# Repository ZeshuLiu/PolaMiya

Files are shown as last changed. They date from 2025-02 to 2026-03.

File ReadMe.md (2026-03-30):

# PolaMiya - 宝丽来相机改装项目

**代码仓库：[PolaMiyaSoftware](https://github.com/ZeshuLiu/PolaMiyaSoftware)**

**硬件仓库（电路及结构）：[PolaMiyaHardware](https://github.com/ZeshuLiu/PolaMiyaHardware)**

> 本仓库保留项目整体说明，代码和硬件设计文件已分别迁移至上述独立仓库。

宝丽来相机一台，具有测距、电动吐片等功能。

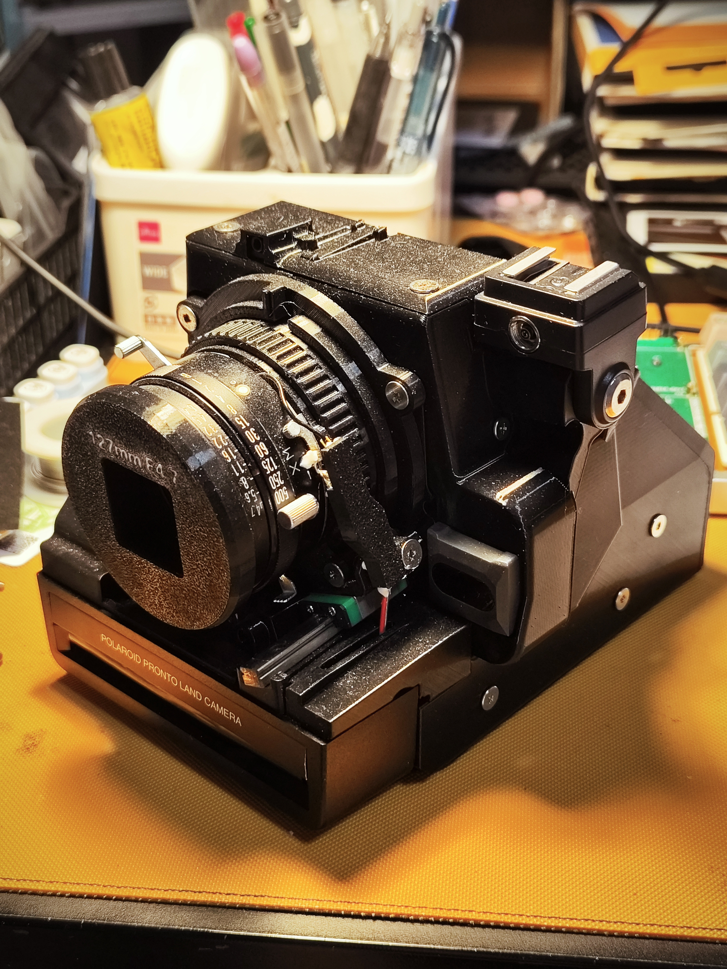
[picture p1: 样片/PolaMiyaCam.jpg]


## 已实现功能

1. 电动吐片
2. 激光测距
3. 温度显示（核心 PCB 及芯片温度）
4. 屏幕显示控制
5. 闪光灯控制（经 MCU）

## 说明

项目比较简单，需要采购的大件只有两个：
- Mamiya Press 127mm 镜头（不需要调焦桶）
- 宝丽来 AF5000（需要里面的吐片下巴、吐片电机和齿轮组）

详细的结构件和装配说明请参考 **[PolaMiyaHardware](https://github.com/ZeshuLiu/PolaMiyaHardware)** 仓库。

## 硬件设计

电路及结构设计文件位于 **[PolaMiyaHardware](https://github.com/ZeshuLiu/PolaMiyaHardware)** 仓库，包含：
- PCB 设计
- 3D 打印结构件
- 装配图纸

## 软件代码

源代码位于 **[PolaMiyaSoftware](https://github.com/ZeshuLiu/PolaMiyaSoftware)** 仓库，包含：
- 主控器固件（MainController2）
- 电源管理固件（PowerManage2）
- CubeMX 配置及 Keil uVision 工程

## 使用方法

机身左下角按钮长按 2 秒开机或关机；三向按钮长按中键 2 秒吐片电机开始运行，随后短按吐片电机停止；在吐片电机运行时推动侧面推杆，相纸即吐出；测距开机即运行。

## 样片

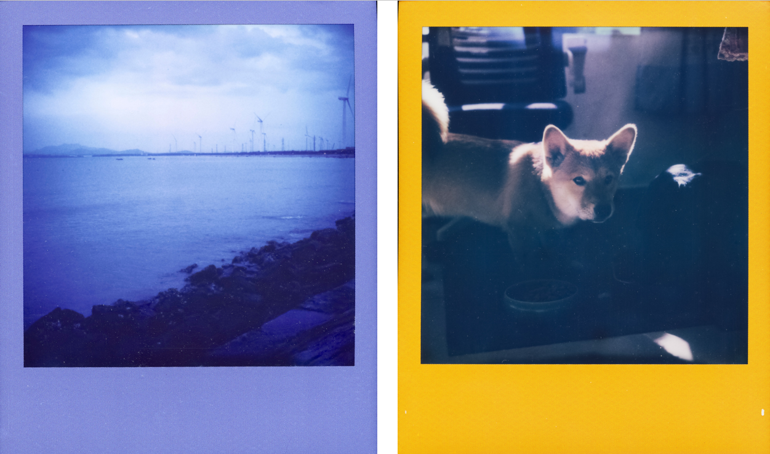
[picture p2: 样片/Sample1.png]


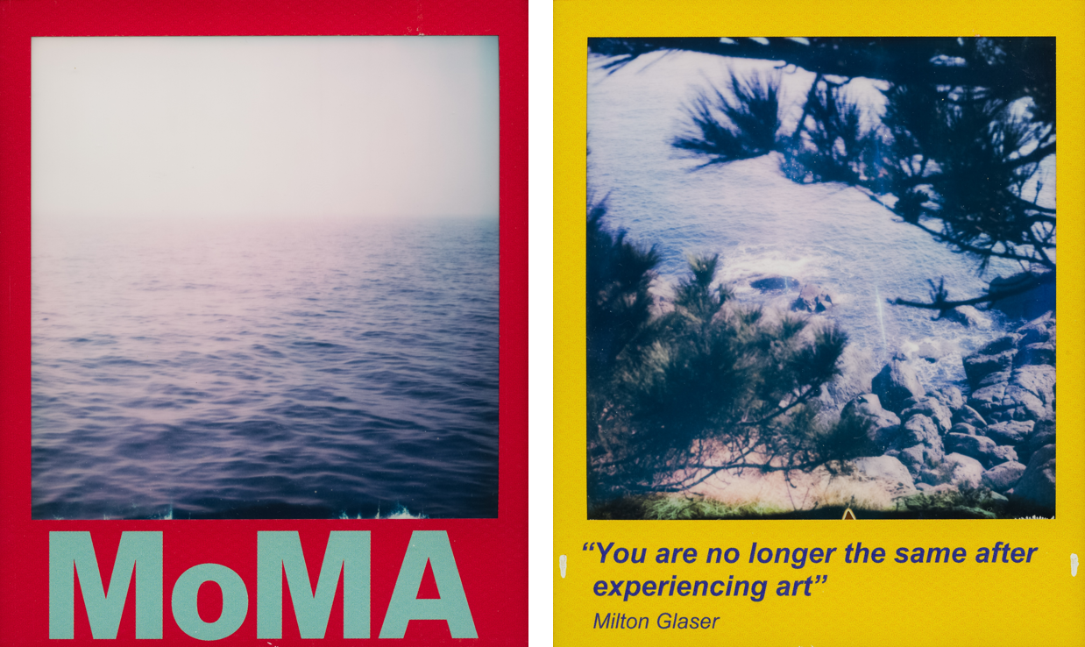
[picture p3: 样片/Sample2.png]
样片 2


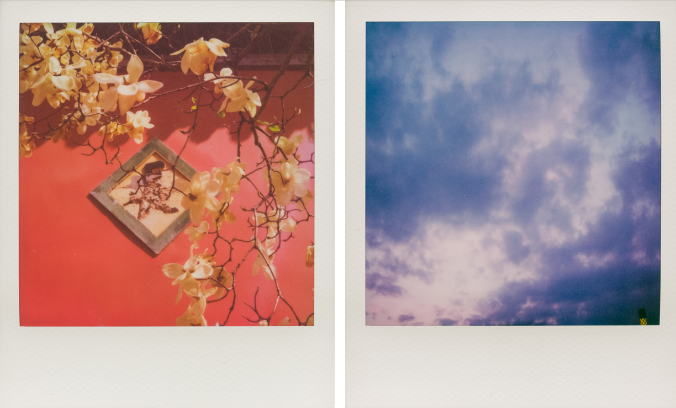
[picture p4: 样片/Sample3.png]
样片 3


## 后续计划

1. 测光
2. 全息取景器（已开始设计）

## 已知问题

1. 吐片口密封性能不好，严禁在有相纸的情况下打开片仓（不中途打开片仓密封性没有问题）

## 已修复问题

1. （主控器 Rev1.0 硬件）相机吐片电机运行后会导致测距停止，该问题由硬件导致，已经在 Rev1.2 硬件中修复
2. （主控器 Rev1.0 硬件）温度传感器布置位置不合理，测得的温度受芯片运行发热影响较大。已经在 Rev1.2 硬件中修复

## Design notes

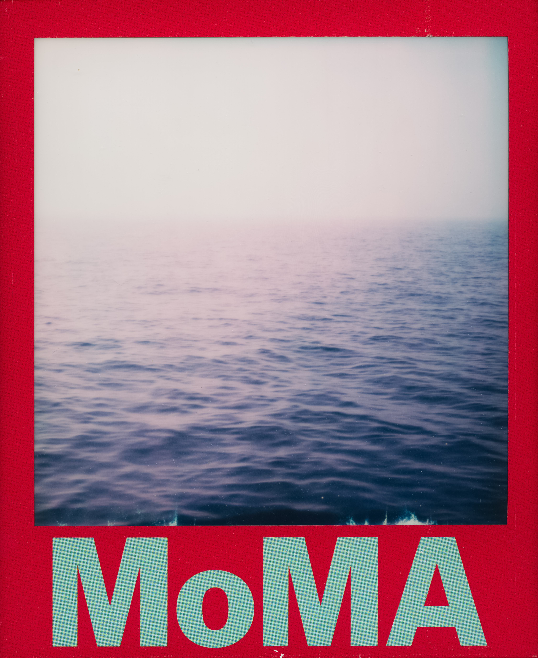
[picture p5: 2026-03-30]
样片/20260329-raw0098.jpg

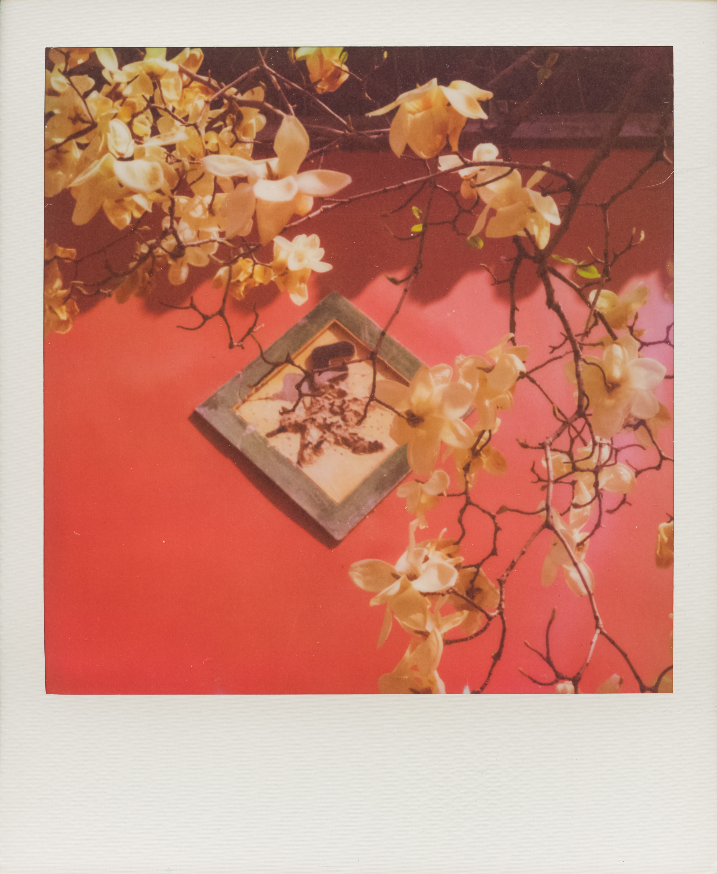
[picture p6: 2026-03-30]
样片/20260329-raw0103.jpg

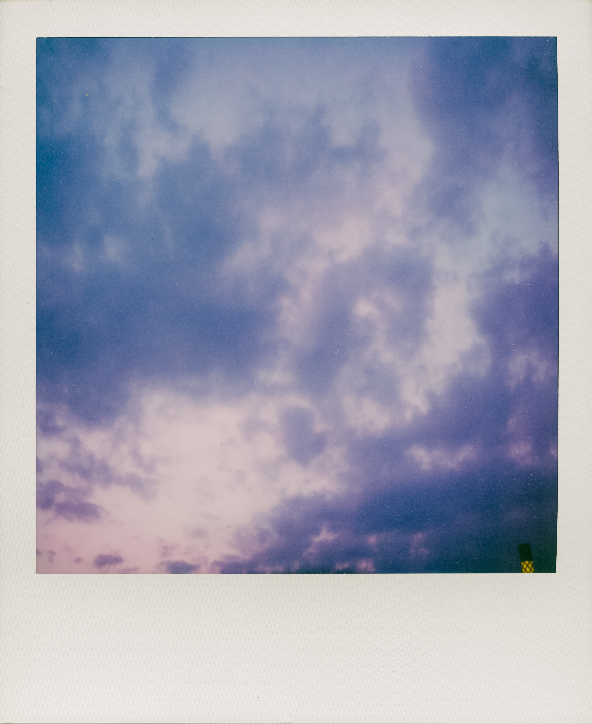
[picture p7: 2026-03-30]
样片/20260329-raw0106.jpg

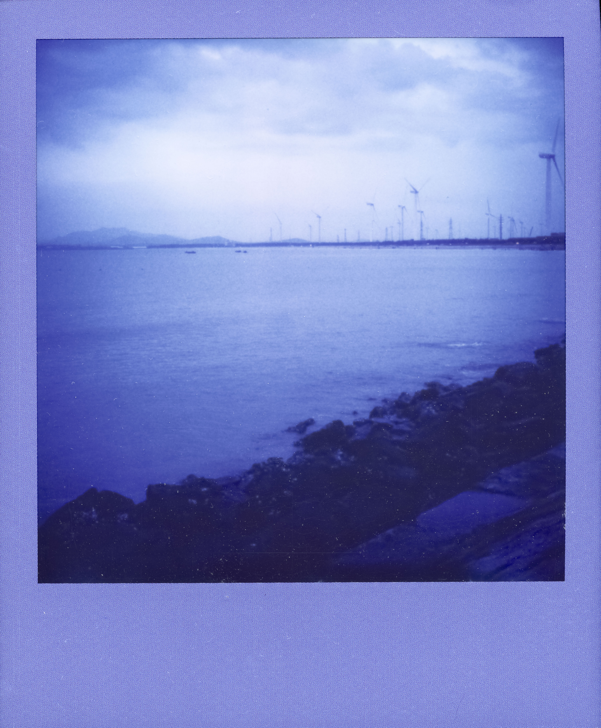
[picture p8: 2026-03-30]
样片/raw0060_1.jpg

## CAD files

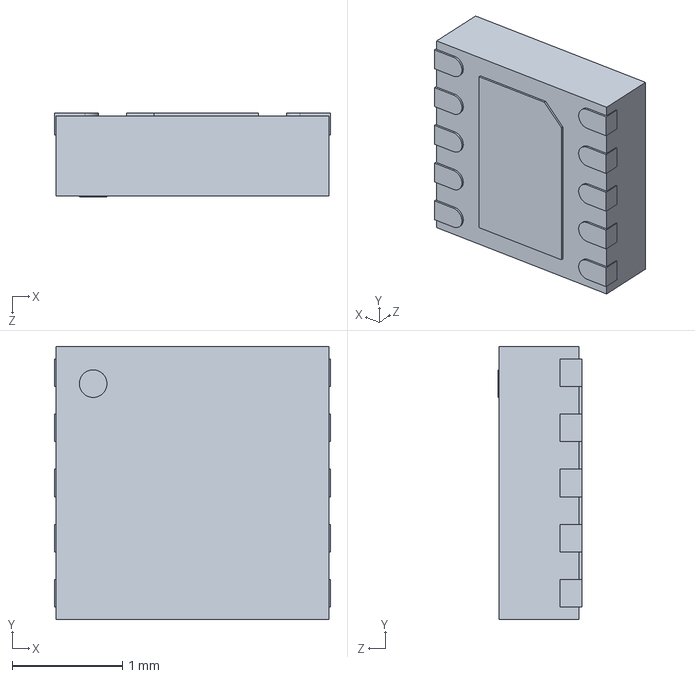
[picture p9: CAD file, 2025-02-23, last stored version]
结构Rev2/电路/机身主控/CQ assembly.SLDPRT
2.50 x 2.47 x 0.76 mm

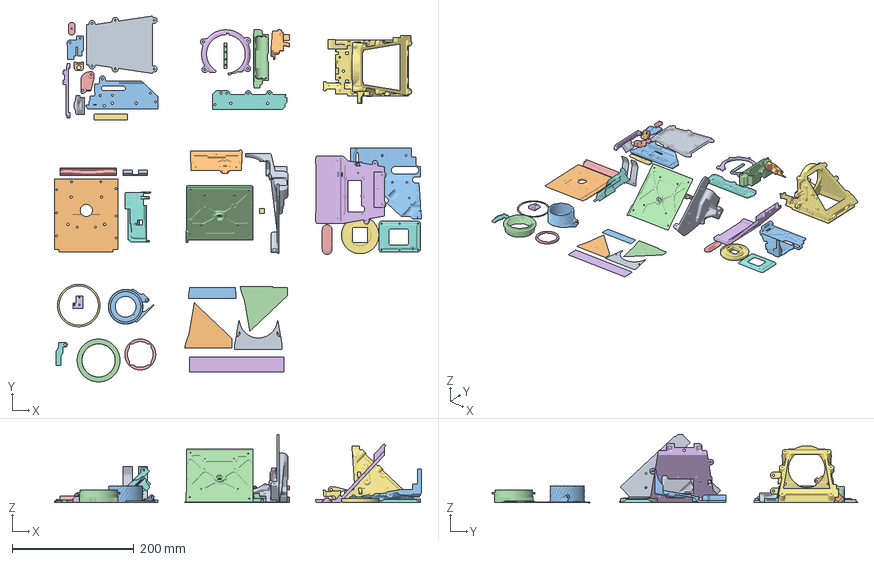
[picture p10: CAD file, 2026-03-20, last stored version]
结构Rev2N/PolaMiya_FullAssemble.3mf
602.8 x 600.9 x 112.5 mm
反光镜盖板.STL
前左盖.STL
右侧板.STL
后侧板.STL
齿轮盖.STL
调焦桶盖.STL
出片推杆.STL
左侧板.STL
齿轮维护盖.STL
电机卡环.STL
推杆外框.STL
推片钩衬垫.STL
推片把手.STL
电池压板.STL
主片仓.STL
前盖板.STL
片仓弹簧.STL
底板.STL
右侧壳.STL
底壳.STL
推片杆外罩.STL
背壳.STL
镜头挡光板.STL
屏幕盖.STL
左侧壳.STL
顶壳.STL
MamiyaPressLensSeat.STL
内环.STL
挡板.STL
滑块连接.STL
镜头衬垫.STL
闪光灯线.STL
前侧.STL
右内壁.STL
后侧.STL
左内壁.STL
齿轮定位.STL
镜筒.STL
按钮.STL

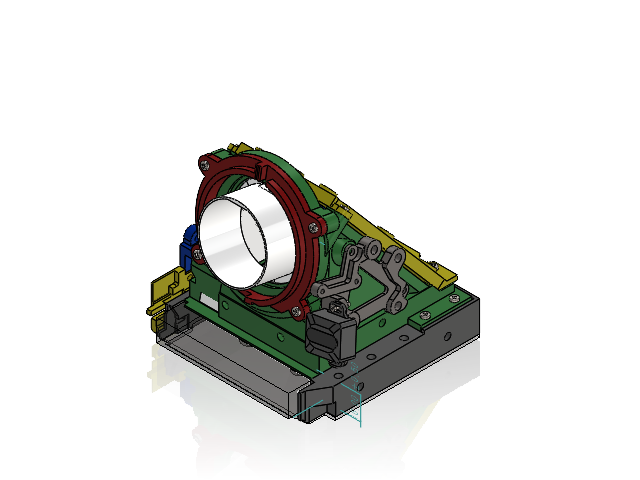
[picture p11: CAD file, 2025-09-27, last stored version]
结构/片仓/片仓1.SLDASM
片仓主框
调焦桶盖
出片推杆
反射镜压板
反射镜压板盖
片仓侧杆
片仓中框
推片把手
推片钩定位
相纸盒
主反射镜
推片勾
cross recessed cheese head screws type a gb x 23
左侧副支架
激光测距SDM18
片仓地板
推杆外框
镜头遮光内筒
片仓消光绒1
片仓消光绒2
片仓消光绒3
片仓消光绒4 x 2
片仓消光绒5

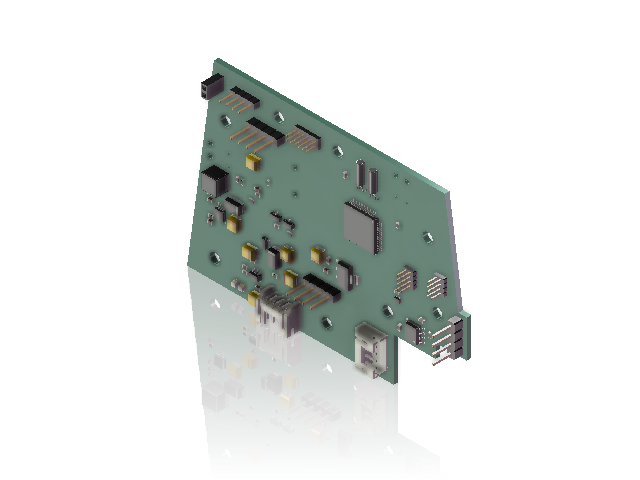
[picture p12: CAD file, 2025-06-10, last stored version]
结构/电路/PM_Controller_R1_0/PM_Controller_Rev1_0.SLDASM
PinHeader_2x04_P1.27mm_Vertical.step x 2
R_0603_1608Metric.step x 42
C_0603_1608Metric.step x 30
SOT-23.step x 6
LQFP-64_10x10mm_P0.5mm.step
PinHeader_1x04_P2.00mm_Vertical.step
PinHeader_2x06_P1.27mm_Vertical.step
CP_EIA-3528-21_Kemet-B.step x 8
PinHeader_1x04_P2.54mm_Vertical.step x 3
LED_0805_2012Metric.step x 2
SOIC-8_3.9x4.9mm_P1.27mm.step x 2
SOT-23-6.step
JST_PH_S4B-PH-K_1x04_P2.00mm_Horizontal.step x 2
D_SMA.step x 3
SOT-563.step
Crystal_C26-LF_D2.1mm_L6.5mm_Horizontal.step x 3
SOT-223.step
PinSocket_1x02_P2.00mm_Vertical.step
L_APV_ANR5040.step
VSSOP-8_3x3mm_P0.65mm.step
TSSOP-14_4.4x5mm_P0.65mm.step
SOT-23-5.step
MFSOP6-4_4.4x3.6mm_P1.27mm.step
L_0805_2012Metric.step
PM_Controller_PCB.step

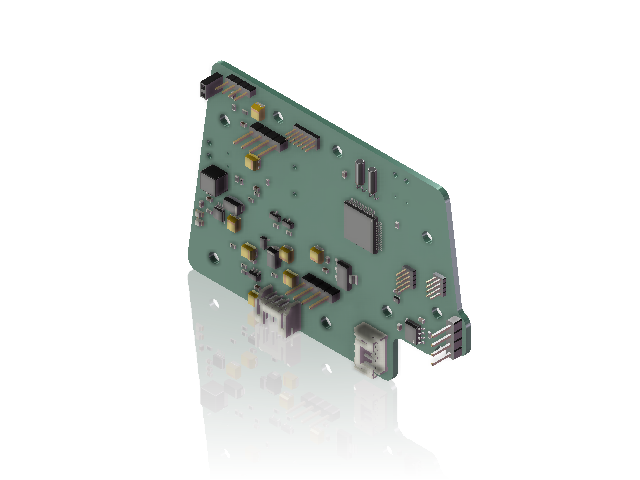
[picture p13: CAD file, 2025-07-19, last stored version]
结构/电路/PM_Controller_R1_1/PM_Controller1_1.SLDASM
PinHeader_2x04_P1.27mm_Vertical.step x 2
R_0603_1608Metric.step x 44
C_0603_1608Metric.step x 32
SOT-23.step x 6
LQFP-64_10x10mm_P0.5mm.step
PinHeader_1x04_P2.00mm_Vertical.step
PinHeader_2x06_P1.27mm_Vertical.step
CP_EIA-3528-21_Kemet-B.step x 9
PinHeader_1x04_P2.54mm_Vertical.step x 3
LED_0805_2012Metric.step x 2
SOIC-8_3.9x4.9mm_P1.27mm.step x 2
SOT-23-6.step
JST_PH_S4B-PH-K_1x04_P2.00mm_Horizontal.step x 2
D_SMA.step x 3
SOT-563.step
Crystal_C26-LF_D2.1mm_L6.5mm_Horizontal.step x 3
SOT-223.step
PinSocket_1x02_P2.00mm_Vertical.step
L_APV_ANR5040.step
VSSOP-8_3x3mm_P0.65mm.step
TSSOP-14_4.4x5mm_P0.65mm.step
SOT-23-5.step
MFSOP6-4_4.4x3.6mm_P1.27mm.step
L_0805_2012Metric.step
PM_Controller_PCB.step

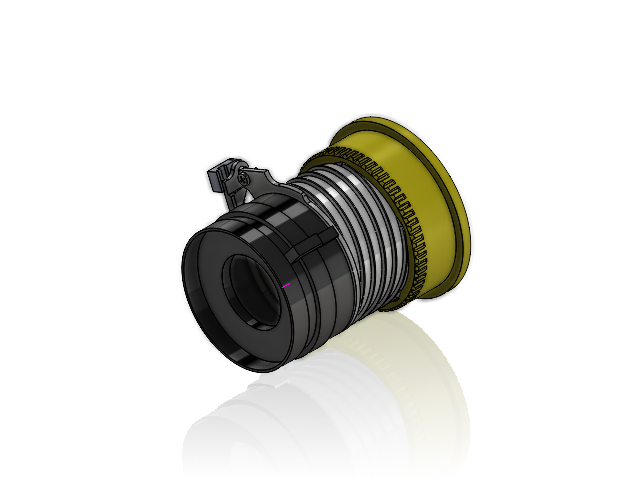
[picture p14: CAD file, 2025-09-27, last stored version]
结构/镜头总成/lensASM.SLDASM
内环
MamiyaPress127
MamiyaPressLensSeat
滑块连接
MGN7C
cross recessed cheese head screws type a gb x 6
闪光灯线

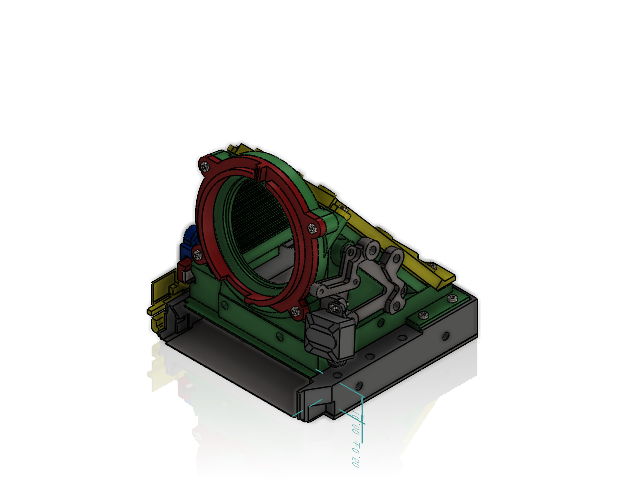
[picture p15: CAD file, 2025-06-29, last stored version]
结构Rev2/片仓/片仓1.SLDASM
片仓主框
调焦桶盖
出片推杆
反射镜压板
反射镜压板盖
片仓侧杆
片仓中框
推片把手
推片钩定位
主反射镜
推片勾
cross recessed cheese head screws type a gb x 23
推片勾内密封
左侧副支架
激光测距SDM18
片仓地板
推杆外框

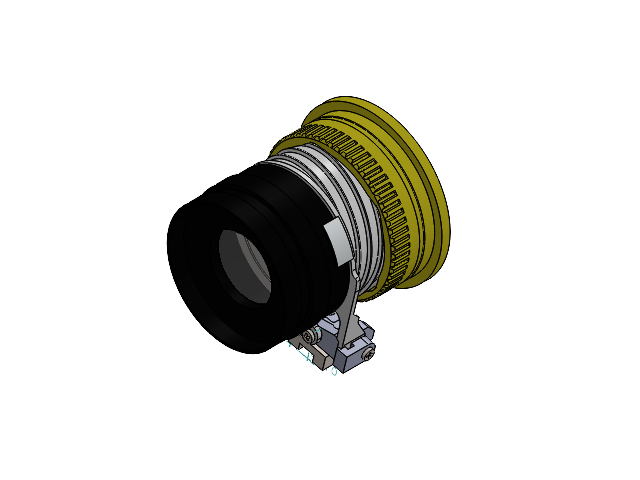
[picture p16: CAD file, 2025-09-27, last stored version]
结构Rev2/镜头总成/lensASM.SLDASM
内环
MamiyaPress127
MamiyaPressLensSeat
滑块连接
MGN7C
cross recessed cheese head screws type a gb x 6
闪光灯线

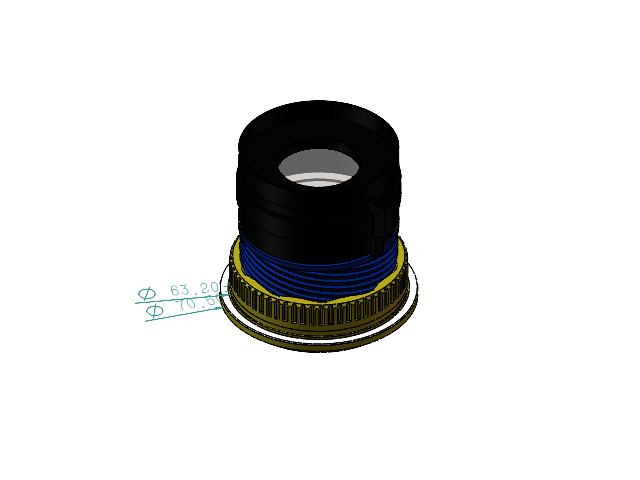
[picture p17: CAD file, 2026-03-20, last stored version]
结构Rev2N/镜头总成/镜头总成.SLDASM
内环
MamiyaPressLensSeat
滑块连接
MamiyaPress127
MGN7C
镜头衬垫

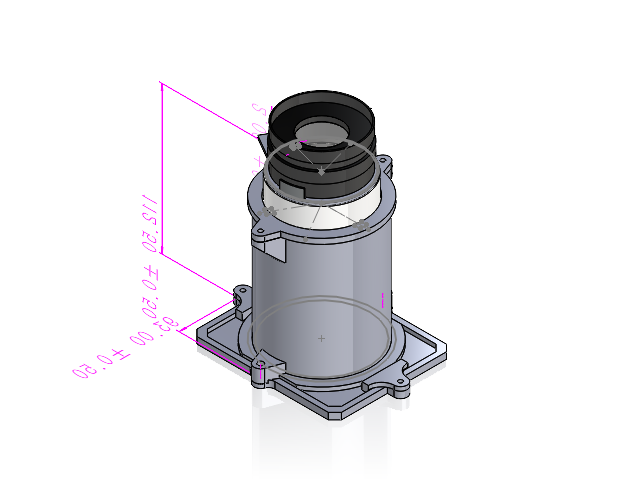
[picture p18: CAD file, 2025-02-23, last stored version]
结构Rev2/测试用/法兰距测试/法兰距测试.SLDASM
镜筒
内环
MamiyaPress127
MamiyaPressLensSeat
盖板
对焦框10080
对焦玻璃压板 x 2

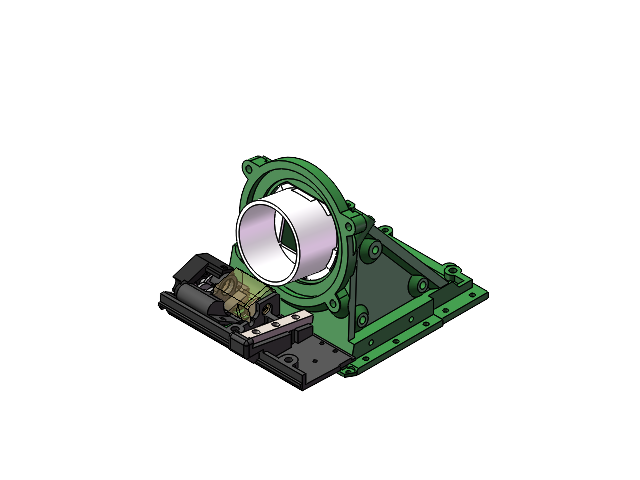
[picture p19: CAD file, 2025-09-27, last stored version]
结构Rev2/片仓吐片总成/片仓吐片装配.SLDASM
片仓吐片一体2^片仓吐片一体
马达座
MG825
吐片上巴
齿轮A
齿轮B
齿轮C
齿轮D
齿轮E
齿轮罩
吐片钣金固定销
MGN7导轨
吐片钣金固定销R
镜头遮光内筒

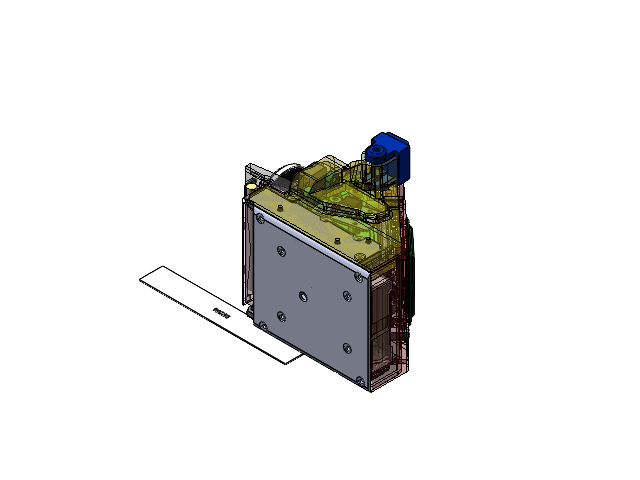
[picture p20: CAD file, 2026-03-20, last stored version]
结构Rev2N/装配.SLDASM
主片仓
主反射镜
相纸盒
吐片口机身钣金-拆机
MG825-拆机
1.6x20.6-拆机
齿轮A-拆机
1.6x14.6-拆机
齿轮B-拆机
齿轮C-拆机
齿轮D-拆机
齿轮E-拆机
PinHeader_2x04_P1.27mm_Vertical.step x 2
R_0603_1608Metric.step x 42
C_0603_1608Metric.step x 30
SOT-23.step x 6
LQFP-64_10x10mm_P0.5mm.step
PinHeader_1x04_P2.00mm_Vertical.step
PinHeader_2x06_P1.27mm_Vertical.step
CP_EIA-3528-21_Kemet-B.step x 8
PinHeader_1x04_P2.54mm_Vertical.step x 3
LED_0805_2012Metric.step x 2
SOIC-8_3.9x4.9mm_P1.27mm.step x 2
SOT-23-6.step
JST_PH_S4B-PH-K_1x04_P2.00mm_Horizontal.step x 2
D_SMA.step x 3
SOT-563.step
Crystal_C26-LF_D2.1mm_L6.5mm_Horizontal.step x 3
SOT-223.step
PinSocket_1x02_P2.00mm_Vertical.step
L_APV_ANR5040.step
VSSOP-8_3x3mm_P0.65mm.step
TSSOP-14_4.4x5mm_P0.65mm.step
SOT-23-5.step
MFSOP6-4_4.4x3.6mm_P1.27mm.step
L_0805_2012Metric.step
PM_Controller_PCB.step
反光镜盖板
推片勾
MGN7导轨1
调焦桶盖
出片推杆
推片把手
齿轮盖
推片钩衬垫
电机卡环
齿轮维护盖
右侧板
18650电池
后侧板
电池负极弹片
电池正极弹片
激光测距SDM18
D_SOD_323.step x 2
CP_Elec_63x77.step x 2
C_1206_3216Metric-0.step x 2
R_0603_1608Metric-1.step x 4
LED_0805_2012Metric-2.step x 2
L_APV_APH1265-3.step
_autosave-MotroDrive_PCB.step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

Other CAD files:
结构Rev2N/电路/PM_Controller_R1_0/PM_Controller_Rev1_0.SLDASM
结构Rev2N/电路/机身主控/Hirose_FH12-8S-0.5SH_1x08-1MP_P0.50mm_Horizontal.SLDASM
结构Rev2N/电路/机身主控/TSSOP-14_4.4x5mm_P0.65mm.SLDASM
电路/sdm18串口.SLDPRT
电路/主控器/DispKey/DispKeyR1_0.step
电路/电机驱动/MotroDrive/Model/MotroDrive.step
电路/闪光灯转接/FlashAdapter/FlashAdapter.step
电路/闪光灯转接/FlashAdapter/upper.SLDPRT
结构/t/PolamiaPCB.SLDASM
结构/t/PolamiaPCB.step
结构/主电子总成/18650电池.SLDPRT
结构/原厂零件/吐片口机身钣金.SLDPRT
结构/吐片机构/1.6x14.6.SLDPRT
结构/吐片机构/1.6x20.6.SLDPRT
结构/吐片机构/MG825.SLDPRT
结构/吐片机构/STLs/1吐片钣金固定销.3mf
结构/吐片机构/STLs/1吐片钣金固定销.STL
结构/吐片机构/STLs/1固定销+2钣金连接.3mf
结构/吐片机构/STLs/2吐片钣金连接件.3mf
结构/吐片机构/STLs/2吐片钣金连接件.STL
结构/吐片机构/STLs/3A齿轮罩.3mf
结构/吐片机构/STLs/3A齿轮罩.STL
结构/吐片机构/STLs/3齿轮罩.3mf
结构/吐片机构/STLs/3齿轮罩.STL
结构/吐片机构/STLs/4马达座.STL
结构/吐片机构/STLs/5马达座.3mf
结构/吐片机构/STLs/5马达座.STL
结构/吐片机构/STLs/6吐片上巴+5线轴.3mf
结构/吐片机构/STLs/6吐片上巴.3mf
结构/吐片机构/STLs/6吐片上巴.STL
结构/吐片机构/STLs/吐片齿轮总成.3mf
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

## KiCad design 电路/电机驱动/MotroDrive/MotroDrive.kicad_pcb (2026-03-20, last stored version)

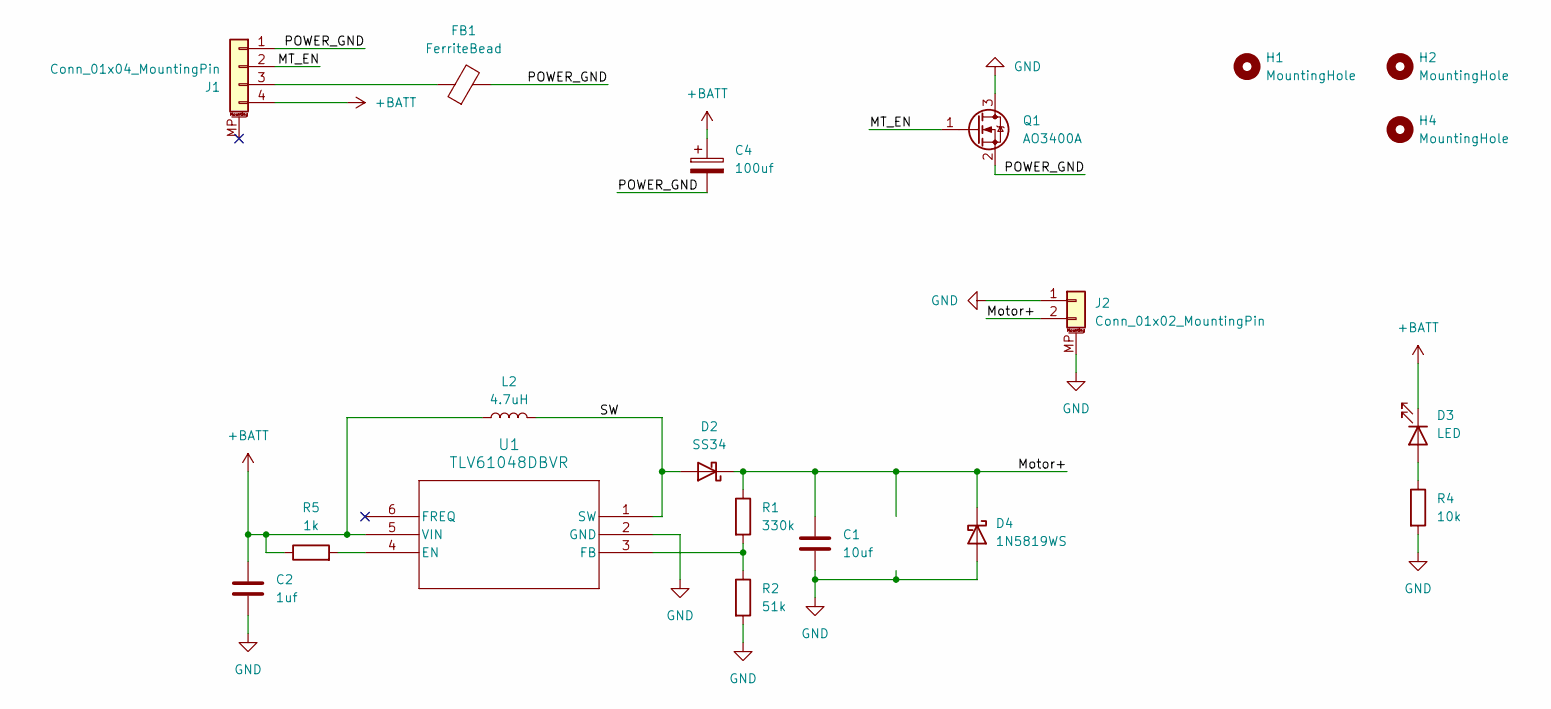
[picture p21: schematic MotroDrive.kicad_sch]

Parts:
C1: 10uf; C_1206_3216Metric_Pad1.33x1.80mm_HandSolder
C2: 1uf; C_1206_3216Metric_Pad1.33x1.80mm_HandSolder
C4: 100uf; CP_Elec_6.3x7.7
D2: SS34; D_SMA
D3: LED; LED_0805_2012Metric_Pad1.15x1.40mm_HandSolder
D4: 1N5819WS; D_SOD-323_HandSoldering
FB1: FerriteBead; L_0603_1608Metric
H1, H2, H4: MountingHole; MountingHole_3.2mm_M3
J1: Conn_01x04_MountingPin; JST_PH_S4B-PH-SM4-TB_1x04-1MP_P2.00mm_Horizontal
J2: Conn_01x02_MountingPin; JST_PH_S2B-PH-SM4-TB_1x02-1MP_P2.00mm_Horizontal
L2: 4.7uH; L_APV_APH1265
Q1: AO3400A; SOT-23
R1: 330k; R_0603_1608Metric_Pad0.98x0.95mm_HandSolder
R2: 51k; R_0603_1608Metric_Pad0.98x0.95mm_HandSolder
R4: 10k; R_0603_1608Metric_Pad0.98x0.95mm_HandSolder
R5: 1k; R_0603_1608Metric
U1: TLV61048DBVR; SOT-23-6_DBV_TEX

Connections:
+BATT: C2.1, C4.1, D3.1 (K), J1.4, L2.1, R5.1, U1.5 (VIN)
/MT_EN: J1.2, Q1.1 (G)
/Motor+: C1.1, D2.1 (K), D4.1 (K), J2.2, R1.1
/POWER_GND: C4.2, FB1.2, J1.1, Q1.2 (S)
/SW: D2.2 (A), L2.2, U1.1 (SW)
GND: C1.2, C2.2, D4.2 (A), J2.1, J2.MP (MountPin), Q1.3 (D), R2.2, R4.2, U1.2 (GND)
unnamed: D3.2 (A), R4.1
unnamed: FB1.1, J1.3
unnamed: R5.2, U1.4 (EN)
unnamed: R1.2, R2.1, U1.3 (FB)

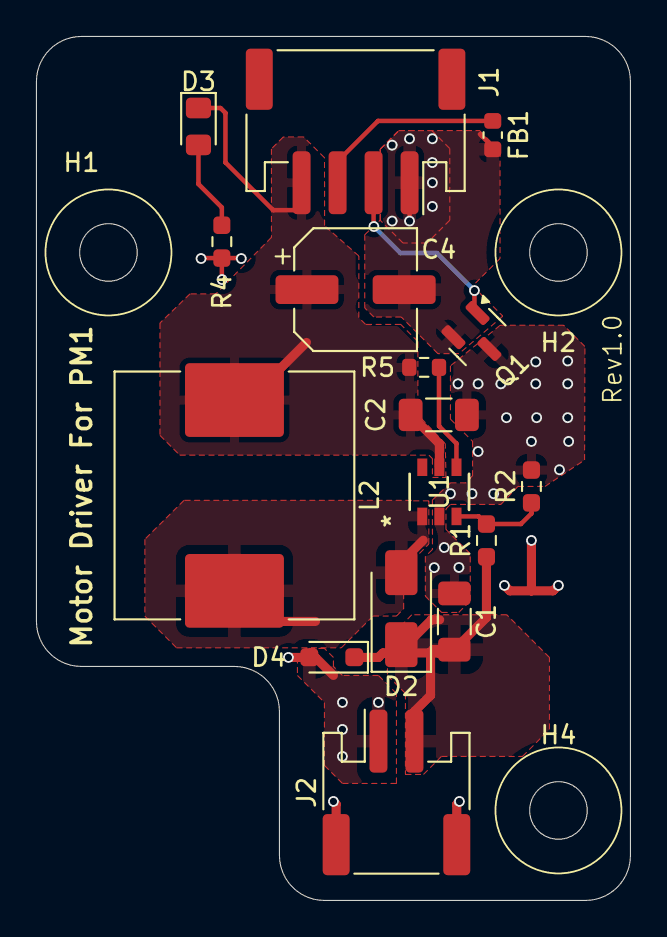
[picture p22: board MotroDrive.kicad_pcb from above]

Board: 2 copper layers, 33.0 x 48.0 mm, 19 parts (0 on the bottom side), 10 nets.

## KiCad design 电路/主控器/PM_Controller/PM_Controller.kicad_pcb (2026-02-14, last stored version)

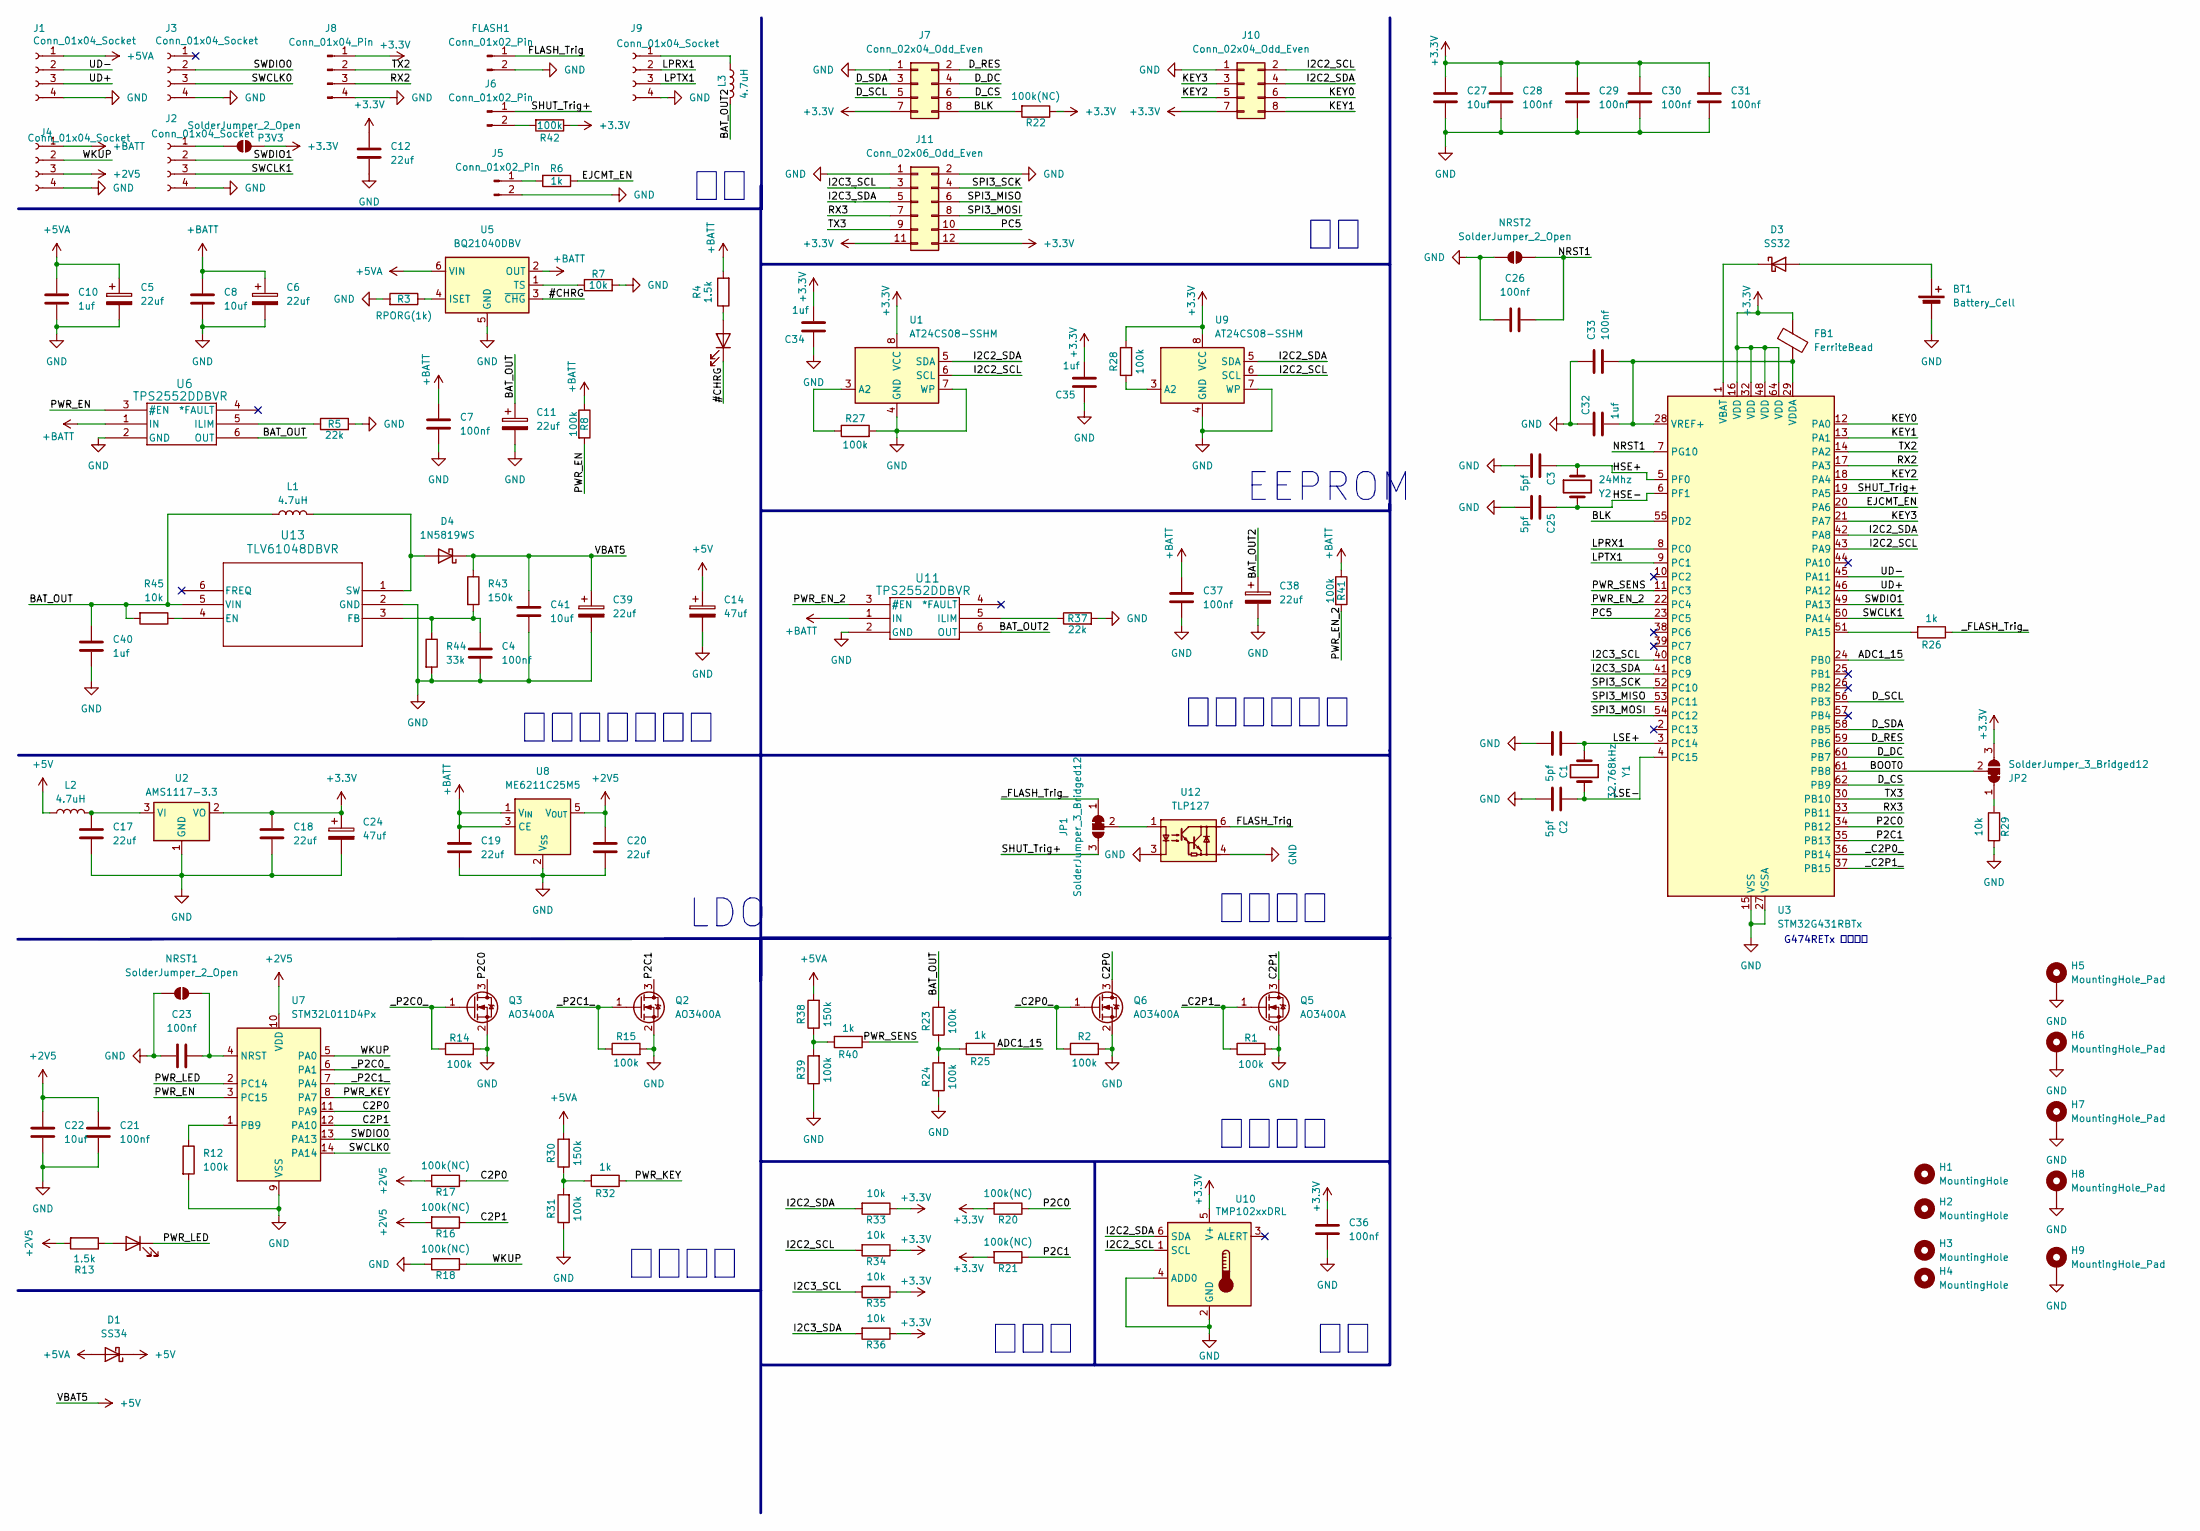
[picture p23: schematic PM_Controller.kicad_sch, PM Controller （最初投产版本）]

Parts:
BT1: Battery_Cell; cr1220
C1, C2, C3, C25: 5pf; C_0603_1608Metric_Pad1.08x0.95mm_HandSolder
C4: 100nf; C_0603_1608Metric
C5, C6, C11, C38: 22uf; CP_EIA-3528-21_Kemet-B_Pad1.50x2.35mm_HandSolder
C7, C21, C23, C26, C28, C29, C30, C31, C33, C36, C37: 100nf; C_0603_1608Metric_Pad1.08x0.95mm_HandSolder
C8, C22, C27: 10uf; C_0603_1608Metric_Pad1.08x0.95mm_HandSolder
C10, C32, C34, C35: 1uf; C_0603_1608Metric_Pad1.08x0.95mm_HandSolder
C12: 22uf; C_1206_3216Metric_Pad1.33x1.80mm_HandSolder
C14, C24: 47uf; CP_EIA-3528-21_Kemet-B_Pad1.50x2.35mm_HandSolder
C17, C18, C19, C20: 22uf; C_0603_1608Metric_Pad1.08x0.95mm_HandSolder
C39: 22uf; CP_EIA-3528-21_Kemet-B_HandSolder
C40: 1uf; C_1206_3216Metric_Pad1.33x1.80mm_HandSolder
C41: 10uf; C_1206_3216Metric_Pad1.33x1.80mm_HandSolder
CHG1: LED; LED_0805_2012Metric_Pad1.15x1.40mm_HandSolder
D1: SS34; D_SMA
D3: SS32; D_SMA_Handsoldering
D4: 1N5819WS; D_SOD-323_HandSoldering
FB1: FerriteBead; L_0805_2012Metric_Pad1.05x1.20mm_HandSolder
FLASH1: Conn_01x02_Pin; SolderWire-0.1sqmm_1x02_P3.6mm_D0.4mm_OD1mm_Relief
H1, H2, H3, H4: MountingHole; MountingHole_3.2mm_M3
H5, H6, H7, H8, H9: MountingHole_Pad; MountingHole_3.2mm_M3_DIN965_Pad_TopBottom
J1, J4: Conn_01x04_Socket; JST_PH_S4B-PH-K_1x04_P2.00mm_Horizontal
J2, J3, J9: Conn_01x04_Socket; PinHeader_1x04_P2.54mm_Vertical
J5: Conn_01x02_Pin; SolderWire-0.5sqmm_1x02_P4.8mm_D0.9mm_OD2.3mm
J6: Conn_01x02_Pin; PinSocket_1x02_P2.00mm_Vertical
J7, J10: Conn_02x04_Odd_Even; PinHeader_2x04_P1.27mm_Vertical
J8: Conn_01x04_Pin; PinHeader_1x04_P2.00mm_Vertical
J11: Conn_02x06_Odd_Even; PinHeader_2x06_P1.27mm_Vertical
JP1, JP2: SolderJumper_3_Bridged12; SolderJumper-3_P1.3mm_Bridged12_Pad1.0x1.5mm
L1, L2, L3: 4.7uH; L_APV_APH0650
NRST1, NRST2: SolderJumper_2_Open; SolderJumper-2_P1.3mm_Open_RoundedPad1.0x1.5mm
P3V3: SolderJumper_2_Open; SolderJumper-2_P1.3mm_Open_RoundedPad1.0x1.5mm
PW_LED1: LED; LED_0805_2012Metric_Pad1.15x1.40mm_HandSolder
Q2, Q3, Q5, Q6: AO3400A; SOT-23
R1, R2, R8, R12, R14, R15, R23, R24, R27, R28, R31, R39, R41, R42: 100k; R_0603_1608Metric_Pad0.98x0.95mm_HandSolder
R3: RPORG(1k); R_0603_1608Metric_Pad0.98x0.95mm_HandSolder
R4, R13: 1.5k; R_0603_1608Metric_Pad0.98x0.95mm_HandSolder
R5, R37: 22k; R_0603_1608Metric_Pad0.98x0.95mm_HandSolder
R6, R25, R26, R32, R40: 1k; R_0603_1608Metric_Pad0.98x0.95mm_HandSolder
R7, R29, R33, R34, R35, R36, R45: 10k; R_0603_1608Metric_Pad0.98x0.95mm_HandSolder
R16, R17, R18, R20, R21, R22: 100k(NC); R_0603_1608Metric_Pad0.98x0.95mm_HandSolder
R30, R38, R43: 150k; R_0603_1608Metric_Pad0.98x0.95mm_HandSolder
R44: 33k; R_0603_1608Metric_Pad0.98x0.95mm_HandSolder
U1, U9: AT24CS08-SSHM; SOIC-8_3.9x4.9mm_P1.27mm
U2: AMS1117-3.3; SOT-223-3_TabPin2
U3: STM32G431RBTx; LQFP-64_10x10mm_P0.5mm
U5: BQ21040DBV; SOT-23-6_Handsoldering
U6, U11: TPS2552DDBVR; DBV0006A_TEX
U7: STM32L011D4Px; TSSOP-14_4.4x5mm_P0.65mm
U8: ME6211C25M5; SOT-23-5_HandSoldering
U10: TMP102xxDRL; SOT-563
U12: TLP127; MFSOP6-4_4.4x3.6mm_P1.27mm
U13: TLV61048DBVR; SOT-23-6_DBV_TEX
Y1: 32.768kHz; Crystal_C26-LF_D2.1mm_L6.5mm_Horizontal
Y2: 24Mhz; Crystal_DS26_D2.0mm_L6.0mm_Horizontal

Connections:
+2V5: C20.1, C21.1, C22.1, J4.3, R13.2, R16.2, R17.2, U7.10 (VDD), U8.5 (V_{OUT})
+3.3V: C12.1, C18.1, C24.1, C27.1, C28.1, C29.1, C30.1, C31.1, C34.2, C35.2, C36.2, FB1.1, J7.7, J8.1, J10.7, J11.11, J11.12, JP2.3 (B), P3V3.2 (B), R20.2, R21.2, R22.1, R28.2, R33.1, R34.1, R35.1, R36.1, R42.1, U1.8 (VCC), U2.2 (VO), U3.16 (VDD), U3.32 (VDD), U3.48 (VDD), U3.64 (VDD), U9.8 (VCC), U10.5 (V+)
+5V: C14.1, C39.1, C41.1, D1.1 (K), D4.1 (K), L2.1, R43.1
+5VA: C5.1, C10.1, D1.2 (A), J1.1, R30.2, R38.2, U5.6 (VIN)
+BATT: C6.1, C7.1, C8.1, C19.1, C37.1, J4.1, R4.2, R8.1, R41.1, U5.2 (OUT), U6.1 (IN), U8.1 (V_{IN}), U8.3 (CE), U11.1 (IN)
/#CHRG: CHG1.1 (K), U5.3 (~CHG)
/ADC1_15: R25.1, U3.24 (PB0)
/BAT_OUT: C11.1, C40.1, L1.1, R23.2, R45.2, U6.6 (OUT), U13.5 (VIN)
/BAT_OUT2: C38.1, L3.2, U11.6 (OUT)
/BLK: J7.8, R22.2, U3.55 (PD2)
/BOOT0: JP2.2 (C), U3.61 (PB8)
/C2P0: Q6.3 (D), R17.1, U7.11 (PA9)
/C2P1: Q5.3 (D), R16.1, U7.12 (PA10)
/D_CS: J7.6, U3.62 (PB9)
/D_DC: J7.4, U3.60 (PB7)
/D_RES: J7.2, U3.59 (PB6)
/D_SCL: J7.5, U3.56 (PB3)
/D_SDA: J7.3, U3.58 (PB5)
/EJCMT_EN: R6.1, U3.20 (PA6)
/FLASH_Trig: FLASH1.1, U12.6
/HSE+: C3.1, U3.5 (PF0), Y2.1
/HSE-: C25.1, U3.6 (PF1), Y2.2
/I2C2_SCL: J10.2, R34.2, U1.6 (SCL), U3.43 (PA9), U9.6 (SCL), U10.1 (SCL)
/I2C2_SDA: J10.4, R33.2, U1.5 (SDA), U3.42 (PA8), U9.5 (SDA), U10.6 (SDA)
/I2C3_SCL: J11.3, R35.2, U3.40 (PC8)
/I2C3_SDA: J11.5, R36.2, U3.41 (PC9)
/KEY0: J10.6, U3.12 (PA0)
/KEY1: J10.8, U3.13 (PA1)
/KEY2: J10.5, U3.18 (PA4)
/KEY3: J10.3, U3.21 (PA7)
/LPRX1: J9.2, U3.8 (PC0)
/LPTX1: J9.3, U3.9 (PC1)
/LSE+: C1.1, U3.3 (PC14), Y1.1
/LSE-: C2.1, U3.4 (PC15), Y1.2
/NRST1: C26.2, NRST2.2 (B), U3.7 (PG10)
/P2C0: Q3.3 (D), R20.1, U3.34 (PB12)
/P2C1: Q2.3 (D), R21.1, U3.35 (PB13)
/PC5: J11.10, U3.23 (PC5)
/PWR_EN: R8.2, U6.3 (#EN), U7.3 (PC15)
/PWR_EN_2: R41.2, U3.22 (PC4), U11.3 (#EN)
/PWR_KEY: R32.1, U7.8 (PA7)
/PWR_LED: PW_LED1.1 (K), U7.2 (PC14)
/PWR_SENS: R40.1, U3.11 (PC3)
/RX2: J8.3, U3.17 (PA3)
/RX3: J11.7, U3.33 (PB11)
/SHUT_Trig+: J6.1, JP1.3 (B), U3.19 (PA5)
/SPI3_MISO: J11.6, U3.53 (PC11)
/SPI3_MOSI: J11.8, U3.54 (PC12)
/SPI3_SCK: J11.4, U3.52 (PC10)
/SWCLK0: J3.3, U7.14 (PA14)
/SWCLK1: J2.3, U3.50 (PA14)
/SWDIO0: J3.2, U7.13 (PA13)
/SWDIO1: J2.2, U3.49 (PA13)
/TX2: J8.2, U3.14 (PA2)
/TX3: J11.9, U3.30 (PB10)
/UD+: J1.3, U3.46 (PA12)
/UD-: J1.2, U3.45 (PA11)
/WKUP: J4.2, R18.1, U7.5 (PA0)
/_C2P0_: Q6.1 (G), R2.1, U3.36 (PB14)
/_C2P1_: Q5.1 (G), R1.1, U3.37 (PB15)
/_FLASH_Trig_: JP1.1 (A), R26.1
/_P2C0_: Q3.1 (G), R14.1, U7.6 (PA1)
/_P2C1_: Q2.1 (G), R15.1, U7.7 (PA4)
GND: BT1.2 (-), C1.2, C2.2, C3.2, C4.2, C5.2, C6.2, C7.2, C8.2, C10.2, C11.2, C12.2, C14.2, C17.2, C18.2, C19.2, C20.2, C21.2, C22.2, C23.1, C24.2, C25.2, C26.1, C27.2, C28.2, C29.2, C30.2, C31.2, C32.1, C33.1, C34.1, C35.1, C36.1, C37.2, C38.2, C39.2, C40.2, C41.2, FLASH1.2, H5.1, H6.1, H7.1, H8.1, H9.1, J1.4, J2.4, J3.4, J4.4, J5.2, J7.1, J8.4, J9.4, J10.1, J11.1, J11.2, NRST1.1 (A), NRST2.1 (A), Q2.2 (S), Q3.2 (S), Q5.2 (S), Q6.2 (S), R1.2, R2.2, R3.2, R5.2, R7.2, R12.2, R14.2, R15.2, R18.2, R24.1, R27.2, R29.2, R31.1, R37.2, R39.1, R44.2, U1.4 (GND), U1.7 (WP), U2.1 (GND), U3.15 (VSS), U3.27 (VSSA), U3.31 (VSS), U3.47 (VSS), U3.63 (VSS), U5.5 (GND), U6.2 (GND), U7.9 (VSS), U8.2 (V_{SS}), U9.4 (GND), U9.7 (WP), U10.2 (GND), U10.4 (ADD0), U11.2 (GND), U12.3, U12.4, U13.2 (GND)
unnamed: BT1.1 (+), D3.2 (A)
unnamed: CHG1.2 (A), R4.1
unnamed: D3.1 (K), U3.1 (VBAT)
unnamed: D4.2 (A), L1.2, U13.1 (SW)
unnamed: J2.1, P3V3.1 (A)
unnamed: J5.1, R6.2
unnamed: J6.2, R42.2
unnamed: J9.1, L3.1
unnamed: JP1.2 (C), U12.1
unnamed: JP2.1 (A), R29.1
unnamed: C23.2, NRST1.2 (B), U7.4 (NRST)
unnamed: PW_LED1.2 (A), R13.1
unnamed: R23.1, R24.2, R25.2
unnamed: R30.1, R31.2, R32.2
unnamed: R38.1, R39.2, R40.2
unnamed: R27.1, U1.3 (A2)
unnamed: C17.1, L2.2, U2.3 (VI)
unnamed: R26.2, U3.51 (PA15)
unnamed: C32.2, C33.2, FB1.2, U3.28 (VREF+), U3.29 (VDDA)
unnamed: R3.1, U5.4 (ISET)
unnamed: R7.1, U5.1 (TS)
unnamed: R5.1, U6.5 (ILIM)
unnamed: R12.1, U7.1 (PB9)
unnamed: R28.1, U9.3 (A2)
unnamed: R37.1, U11.5 (ILIM)
unnamed: R45.1, U13.4 (EN)
unnamed: C4.1, R43.2, R44.1, U13.3 (FB)

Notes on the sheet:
EEPROM
电源管理
接口电平
上下拉
G474RETx 应该可用
相机功能
LDO
电池充电、升压
预留电源输出

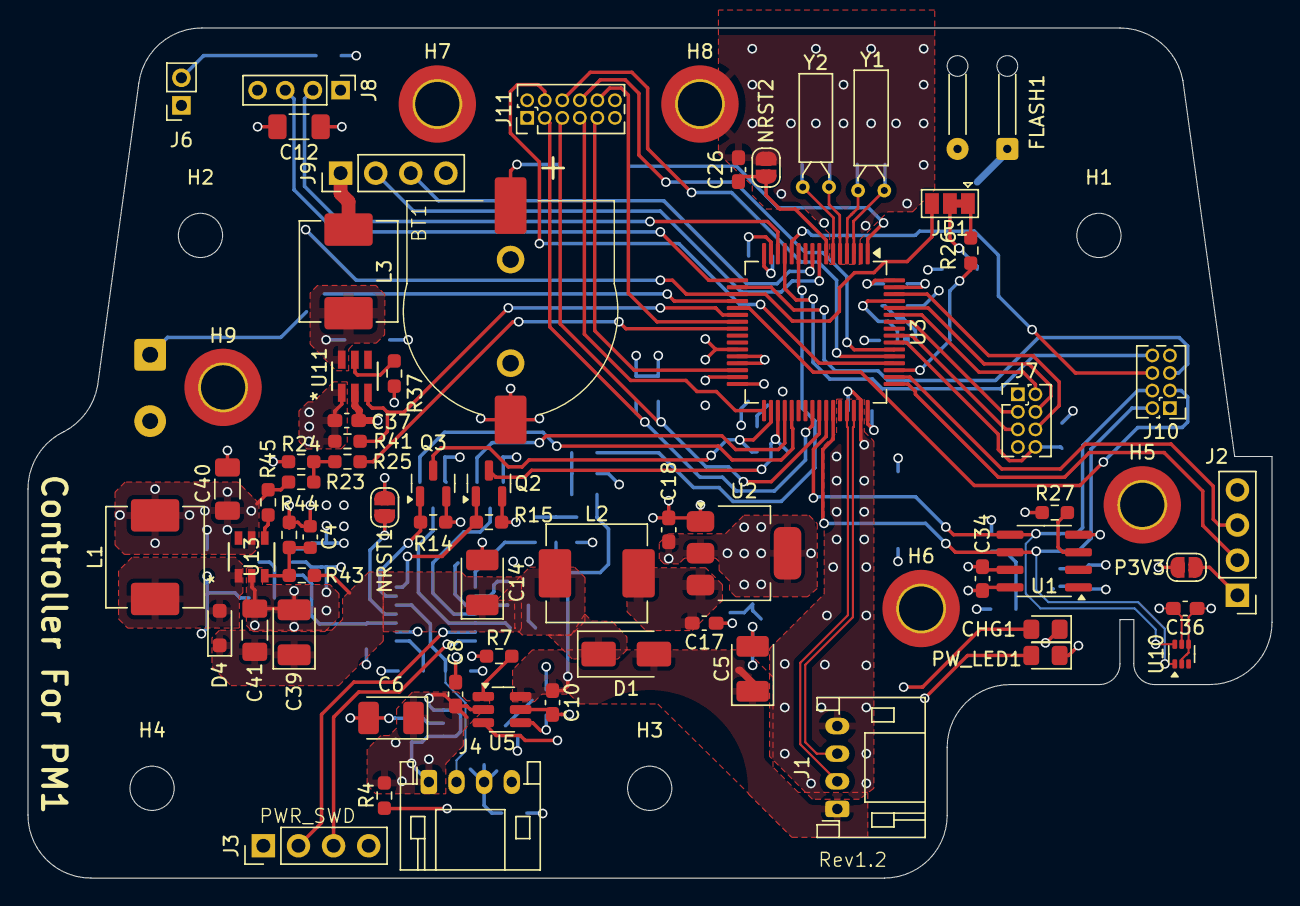
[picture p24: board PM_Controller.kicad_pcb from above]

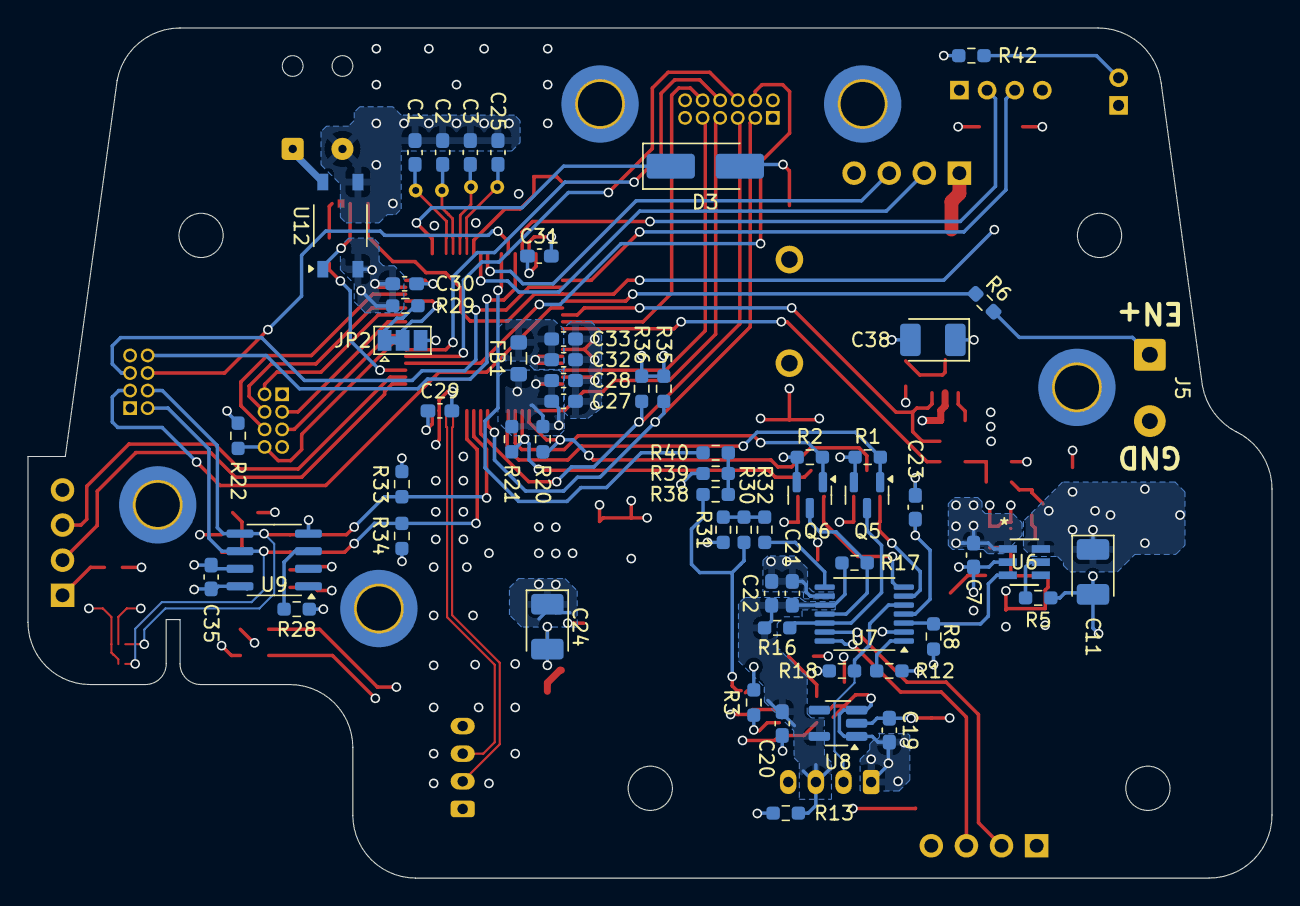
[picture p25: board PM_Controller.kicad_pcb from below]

Board: 4 copper layers, 90.0 x 61.5 mm, 132 parts (59 on the bottom side), 91 nets.

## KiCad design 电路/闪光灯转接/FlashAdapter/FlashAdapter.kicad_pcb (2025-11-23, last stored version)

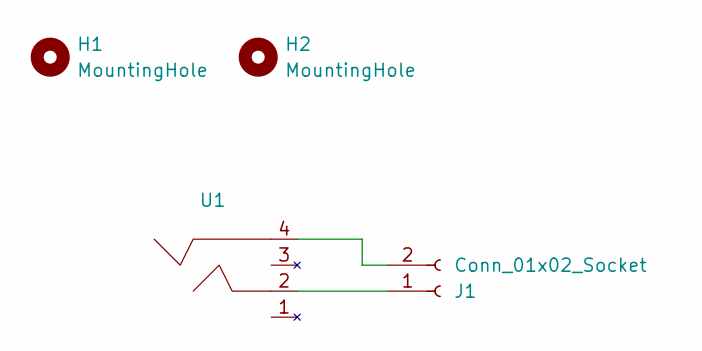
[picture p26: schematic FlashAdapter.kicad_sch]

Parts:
H1, H2: MountingHole; MountingHole_2.7mm_M2.5
J1: Conn_01x02_Socket; SolderWire-0.75sqmm_1x02_P7mm_D1.25mm_OD3.5mm
U1: PJ-218X-SMT

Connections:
unnamed: J1.1, U1.2
unnamed: J1.2, U1.4

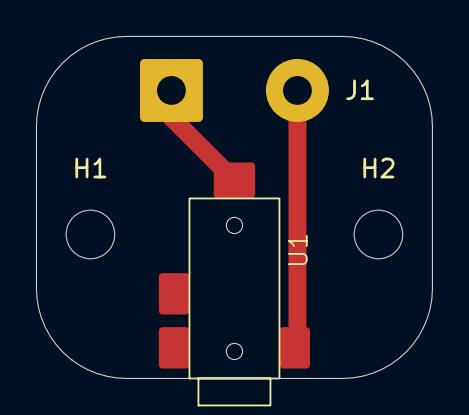
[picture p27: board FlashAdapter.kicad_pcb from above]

Board: 2 copper layers, 22.0 x 19.0 mm, 4 parts (0 on the bottom side), 2 nets.

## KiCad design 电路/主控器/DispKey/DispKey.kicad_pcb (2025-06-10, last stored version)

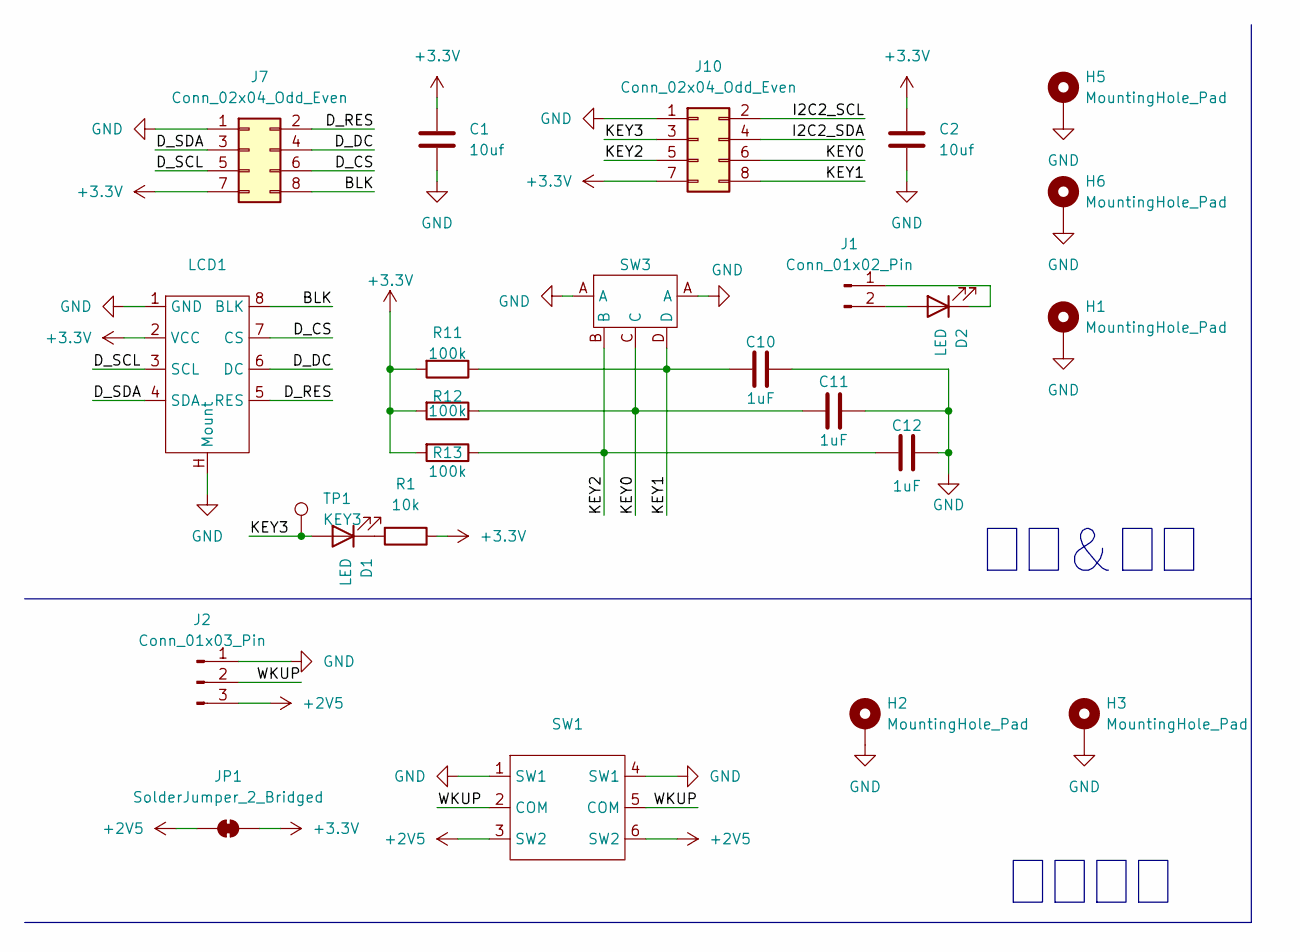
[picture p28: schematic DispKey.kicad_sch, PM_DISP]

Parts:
C1, C2: 10uf; C_0805_2012Metric_Pad1.18x1.45mm_HandSolder
C10, C11, C12: 1uF; C_0603_1608Metric_Pad1.08x0.95mm_HandSolder
D1, D2: LED; LED_0805_2012Metric_Pad1.15x1.40mm_HandSolder
H1: MountingHole_Pad; MountingHole_3.2mm_M3_DIN965_Pad
H2, H3, H5, H6: MountingHole_Pad; MountingHole_2.7mm_M2.5_DIN965_Pad
J1: Conn_01x02_Pin; SolderWire-0.1sqmm_1x02_P3.6mm_D0.4mm_OD1mm
J2: Conn_01x03_Pin; SolderWire-0.1sqmm_1x03_P3.6mm_D0.4mm_OD1mm
J7, J10: Conn_02x04_Odd_Even; PinHeader_2x04_P1.27mm_Vertical
JP1: SolderJumper_2_Bridged; SolderJumper-2_P1.3mm_Bridged2Bar_RoundedPad1.0x1.5mm
LCD1: LCD1.69_240_280
R1: 10k; R_0603_1608Metric_Pad0.98x0.95mm_HandSolder
R11, R12, R13: 100k; R_0603_1608Metric_Pad0.98x0.95mm_HandSolder
SW1: sw_push_5.8x5.8mm
SW3: Direction3 Pin5
TP1: KEY3; TestPoint_Pad_2.0x2.0mm

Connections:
+2V5: J2.3, JP1.1 (A), SW1.3 (SW2), SW1.6 (SW2)
+3.3V: C1.1, C2.1, J7.7, J10.7, JP1.2 (B), LCD1.2 (VCC), R1.1, R11.2, R12.2, R13.2
/BLK: J7.8, LCD1.8 (BLK)
/D_CS: J7.6, LCD1.7 (CS)
/D_DC: J7.4, LCD1.6 (DC)
/D_RES: J7.2, LCD1.5 (RES)
/D_SCL: J7.5, LCD1.3 (SCL)
/D_SDA: J7.3, LCD1.4 (SDA)
/I2C2_SCL: J10.2
/I2C2_SDA: J10.4
/KEY0: C11.1, J10.6, R12.1, SW3.C
/KEY1: C10.1, J10.8, R11.1, SW3.D
/KEY2: C12.1, J10.5, R13.1, SW3.B
/KEY3: D1.2 (A), J10.3, TP1.1
/WKUP: J2.2, SW1.2 (COM), SW1.5 (COM)
GND: C1.2, C2.2, C10.2, C11.2, C12.2, H1.1, H2.1, H3.1, H5.1, H6.1, J2.1, J7.1, J10.1, LCD1.1 (GND), LCD1.H (Mount), SW1.1 (SW1), SW1.4 (SW1), SW3.A
unnamed: D1.1 (K), R1.2
unnamed: D2.2 (A), J1.2
unnamed: D2.1 (K), J1.1

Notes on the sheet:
电源按键
显示&按键

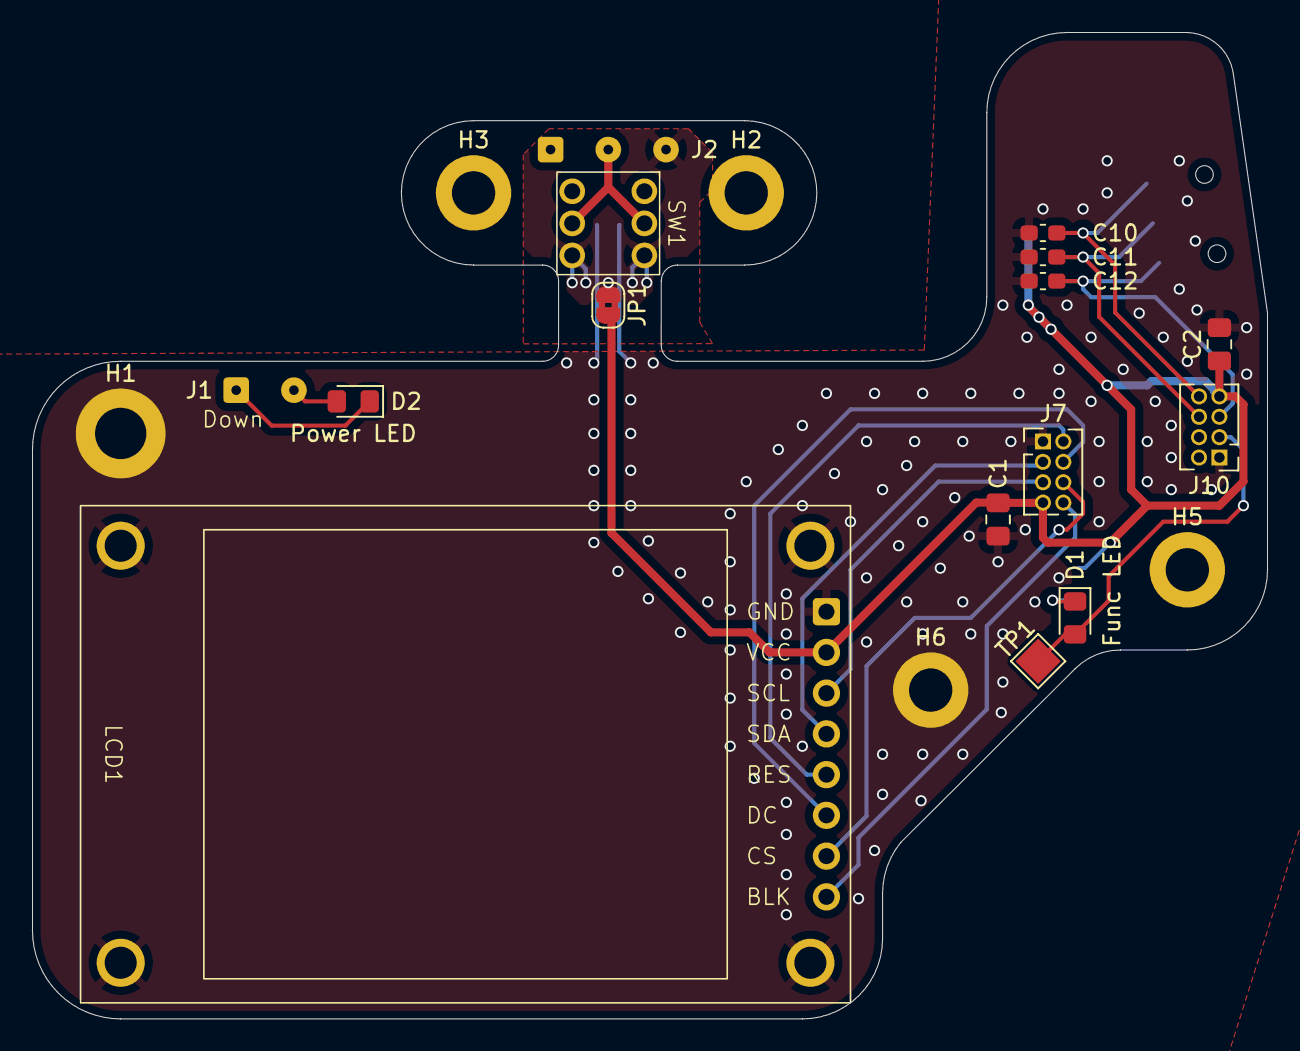
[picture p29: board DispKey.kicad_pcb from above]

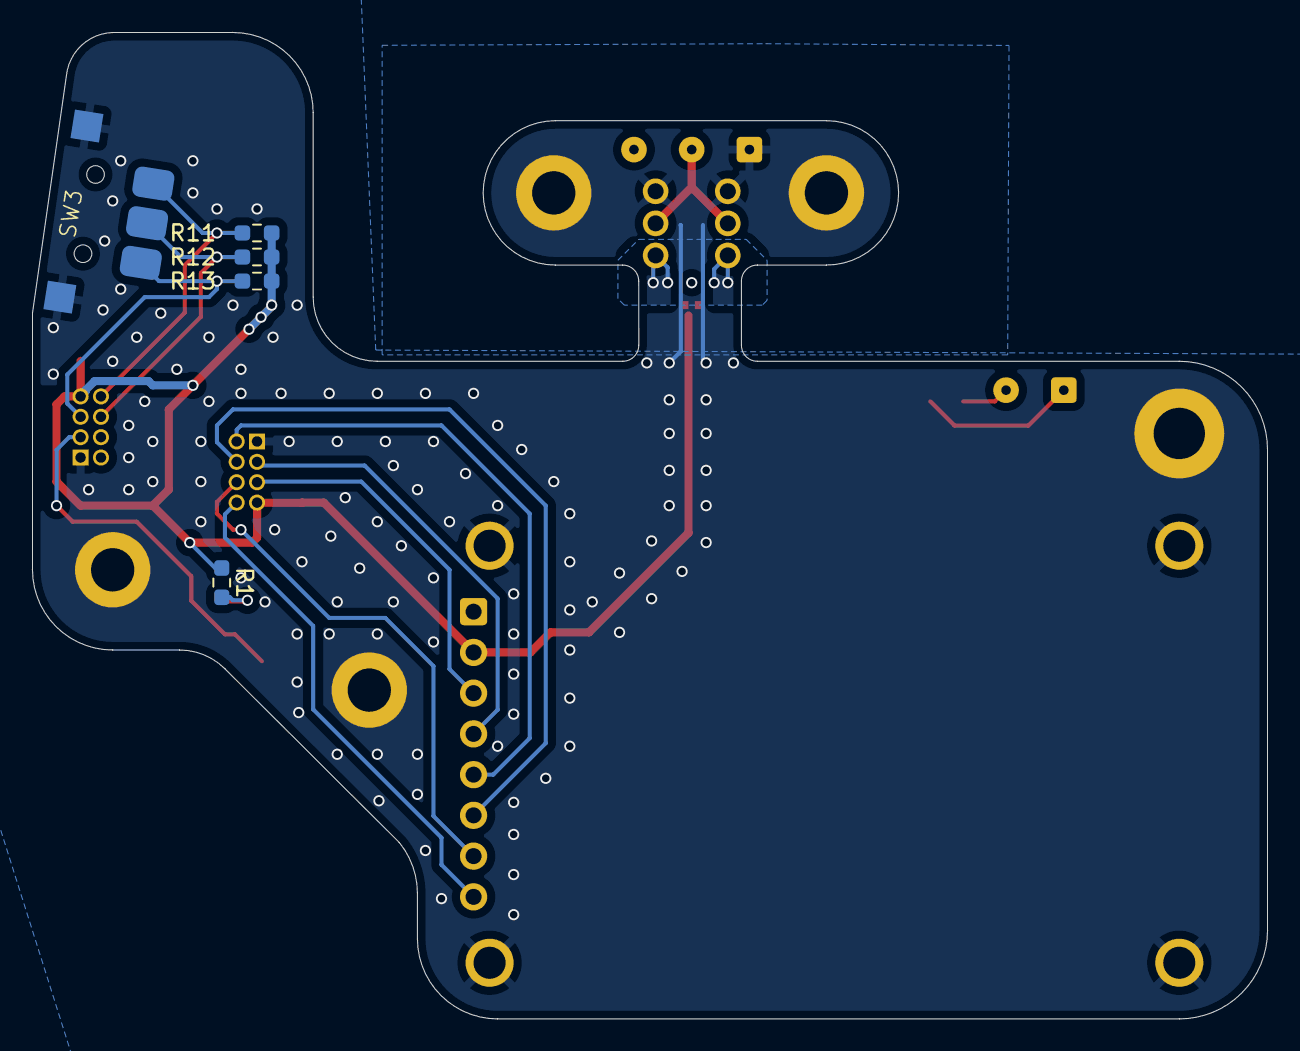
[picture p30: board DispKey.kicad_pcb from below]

Board: 2 copper layers, 77.0 x 61.5 mm, 25 parts (5 on the bottom side), 17 nets.

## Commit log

2025-02-23 消除地板和吐片外壳之间干涉，加固侧边安装孔
    [1.6x14.6.SLDPRT, 1.6x20.6.SLDPRT, 10片仓地板.3mf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]
2025-02-23 更新片仓中框、片仓地板
    [10片仓地板.3mf, 10片仓地板.STL, 5片仓中框.3mf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]
2025-06-23 ZUI init
    [7x7按键.SLDPRT, PM_Controller.kicad_pcb, PM_Controller.kicad_sch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]
2025-06-29 电源显示ok
    [1.69寸彩色TFT.SLDPRT, 7x7按键.SLDPRT, SMT螺母M2.5H3.5.SLDPRT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]
2025-06-29 修复了显示用的数组使用局部变量的问题
2025-07-01 吐片正常（废片测试）
2025-07-01 测距正常，下一步尽量改成用接收到idle，来防止误码。
2025-07-02 显示中加入核心以及PCB温度；后续应考虑测距使用接收到空闲中断避免误码导致中断。
    [吐片机构.SLDASM, 显示壳.3mf, 显示壳.SLDPRT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]
2025-07-16 测距改成300ms一次，解决了测距卡死的问题
2025-07-16 定时器计数逻辑修改
2025-07-16 修复定时器逻辑问题
2025-07-18 吐片后必须要重启电源才能测距
    [PM_Controller.kicad_sch]
2025-07-19 Rev1.0版本可正常工作
    [3A齿轮罩.3mf, 3A齿轮罩.STL, PM_Controller.kicad_pcb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]
2025-09-27 第二代机械结构ok
    [1.69寸彩色TFT.SLDPRT, 1.6x14.6-拆机.SLDPRT, 1.6x14.6.SLDPRT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]
2025-11-23 闪关灯功能OK 准备给电机加一个斜坡
    [FlashAdapter.kicad_pcb, FlashAdapter.kicad_sch, FlashAdapter.step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]
2025-11-23 电机软起动加入，效果有限无法防止激光雷达下电
    [PM_Controller.kicad_sch]
2025-12-25 闪光灯ok
    [MamiyaPressLensSeat.SLDPRT, MamiyaPressLensSeat.STEP, PM_Controller.kicad_pcb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]
2026-01-05 闪光已经就绪，至此基本功能全部OK
    [吐片机构.SLDASM, 左侧壳.3mf, 左侧壳.SLDPRT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]
2026-01-05 清理仓库
    [1.69寸彩色TFT.SLDPRT, 1.6x14.6.SLDPRT, 1.6x20.6.SLDPRT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]
2026-01-21 优化外壳与5V外部供电电路选择逻辑
    [PM_Controller.kicad_pcb, PM_Controller.kicad_sch, 吐片机构.SLDASM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]
2026-01-21 主控升级至Rev1.2，电机驱动 Rev1.1
    电机驱动修改后采用Mosfet控制高侧电源通路。主控配套进行了更改。
    [MotroDrive.kicad_pcb, MotroDrive.kicad_sch, PM_Controller.kicad_pcb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]
2026-02-02 更新了电机驱动以及主控器PCB
    [PM_Controller.kicad_pcb, bomR1.1.csv, bomR1.2.csv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]
2026-02-03 测试Rev1.2版本PCB，吐片导致测距停止问题已经修复
    测试Rev1.2版本PCB
    1. 原有引脚可以直接兼容G474芯片
    2. 吐片导致测距停止问题已经修复
    目前吐片的PWM加载方式可以进行调整
2026-02-03 硬件1.3版本，调整闪光灯为默认过MCU
    [PM_Controller.kicad_pcb, PM_Controller.kicad_sch]
2026-02-08 机械：优化吐片机械结构；代码：吐片电机及屏幕显示逻辑调整，ADC采样逻辑调整
    机械：
    1. 吐片下巴处增加导向齿轮
    代码：
    1. 电机启动斜坡加载速率调整
    2. 充电主控芯片采用外部供电时关闭屏幕及LED闪烁
    3. 电池ADC增加一阶低通滤波
    [MotroDrive.SLDASM, PH2x4.SLDPRT, 取片盒工具.3mf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]
2026-02-14 所有修改，两盒底片测试OK
    [片仓总成.SLDASM]
2026-02-27 新版本主片仓以及镜头机构设计，待测试
    主片仓与吐片钣金连接位置内移1.25mm；
    镜头机构重新设计连接机构，期望消除黑底；
    删除了结构吐片机构文件夹（内容早已合并入片仓总成，应删除）
    [1.6x14.6.SLDPRT, 1.6x20.6.SLDPRT, 1吐片钣金固定销.3mf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]
2026-02-27 修复对焦距离问题
    [MamiyaPressLensSeat.SLDPRT, 主片仓.SLDPRT, 内环.SLDPRT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]
2026-03-06 重新整理打印文件
    [MamiyaPressLensSeat.SLDPRT, MamiyaPressLensSeat.STL, PolaMiya_FullAssemble.3mf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]
2026-03-08 新版本PM，解决底部偏暗
    [PolaMiya_FullAssemble.3mf, 前侧.SLDPRT, 前侧.STL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]
2026-03-14 增加多种尺寸的齿轮定位
    [PolaMiya_FullAssemble.3mf, 装配.SLDASM, 镜头总成.SLDASM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]
2026-03-14 原本齿轮定位尺寸ok不应再加高度；修改电机驱动电路，但是电机驱动电路未完全ok
    [MotroDrive.kicad_pcb, MotroDrive.kicad_sch, PolaMiya_FullAssemble.3mf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]
2026-03-14 驱动电路升级至R1.2 未验证
    R1.2 升压二极管改为SS34；储能电容改为连接原始电源GND；电路板改为单面布局
    [MotroDrive.kicad_pcb, MotroDrive.kicad_sch]
2026-03-19 开始设计全息取景器
    [主座.SLDPRT, 主座.STL, 右侧板.STEP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]
2026-03-19 结构CNC条件具备，尚未调整螺纹孔
    [右侧板.SLDPRT, 右侧板.STEP, 左侧板.SLDPRT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]
2026-03-20 添加 Keil 6 CMSIS 配置文件
    [MainController2.cbuild-idx.yml, MainController2.cbuild-pack.yml, MainController2.cproject.yml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]
2026-03-20 升级 Keil 6 (CMSIS) 项目配置
    - 添加 CMSIS 配置文件 (.cmsis/, *.cproject.yml, *.csolution.yml 等)
    - 添加 vcpkg 和 clangd 配置
    - 更新 .gitignore 忽略 log 文件
    - 更新 VS Code 配置
    [片仓总成.SLDASM, 装配.SLDASM, 镜头总成.SLDASM]
2026-03-20 修复 TODO 中所有 P0 问题
    - main.c: 删除未使用的调试变量 a 和 b
    - main.c: 删除未使用的全局变量 test_pin 和 tmp
    - motor.h: 修复宏定义运算符优先级问题 (添加括号)
    - TODO.md: 标记 P0 问题为已修复
2026-03-20 补充提交：项目配置和代码变更
    - .vscode/settings.json: VS Code 设置
    - CLAUDE.md: 项目指南文档
    - gpio.c, motor.c, zui_usr.c: 代码更新
    - MDK-ARM: Keil 项目配置更新
    [MainController2.cbuild-idx.yml, MainController2.cproject.yml, MainController2.csolution.yml]
2026-03-20 Remove code folder, moved to separate software repo
    [MainController2.cbuild-idx.yml, MainController2.cbuild-pack.yml, MainController2.cproject.yml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]
2026-03-20 项目中的代码文件迁出至其它仓库
2026-03-20 移除子模块配置
2026-03-20 更新 README，添加代码仓库链接
2026-03-20 将代码仓库链接移到 README 顶部
2026-03-21 迁移硬件设计文件至独立仓库
    - 将电路设计文件（KiCad 项目）移至 PolaMiyaHardware 仓库
    - 将结构文件（STL/STEP/SolidWorks）移至 PolaMiyaHardware 仓库
    - 更新 ReadMe.md 添加仓库说明和已实现功能
    - 本仓库保留项目整体说明文档
    [1.69寸彩色TFT.SLDPRT, 1.6x14.6-拆机.SLDPRT, 1.6x20.6-拆机.SLDPRT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]
2026-03-30 更新样片
2026-03-30 更新样片展示
2026-03-30 展示相机外观
